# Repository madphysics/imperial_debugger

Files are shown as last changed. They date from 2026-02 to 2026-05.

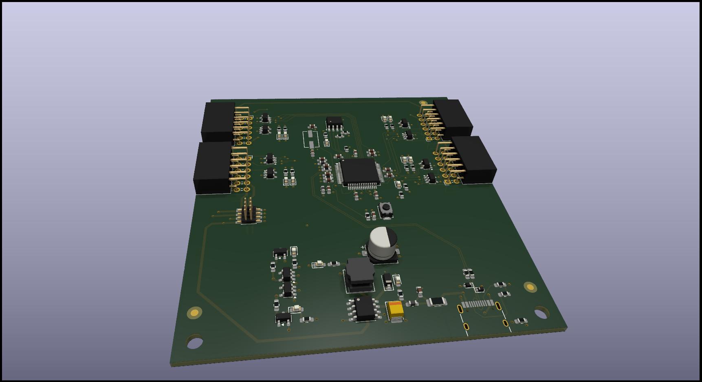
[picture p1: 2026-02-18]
imperial_debugger.jpg

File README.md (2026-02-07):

View this project on [CADLAB.io](https://cadlab.io/project/1894). 

# Imperial Debugger V1.1 #

USB Based multi serial port adaptor

## Overview ##

Based on an FTDI FT4232HL USB to serial chip, with 4 ports. 

The plan is to bring all points to bring them out to a standard 2x6 header

Then can use external daughter boards to do things like:

 * 1x RS232 with hardware flow control
 * 1x RS422/485 with configuration to switch between the two, wither in software or hardware.
 * 1x RS232/422 selectable
 * 1x Logic level, with external level shifter (selectable to internal 3v3)
  
## Power Supply ##

Simple switching mode from 5V USB to 3v3 on the board.
 
## Potential XCVR chips

### RS232
  * TI MAX3222E -- Looks good. Has protection in it. 250k min speeds.
    * MAX3222EEWN is WideSOIC
	  * Also available in SSOP 20 pin, which is harder to solder.
    * 4 signals, so TX/RX and CTS/RTS
	* 3222 has a shutdown pin, Active Low.

### RS422/485

  * MAX3491E
  * MAX22503
  * MAX3070-3073-3076 (3076 is fastest, all pin compatible)
  * SP330 (can do 232 as well, so could use just 3 of these?)
  
### Logic level
 
  * Ideally we want to go from 3v3 ->5V but also 3v3 > lower (2.5, 1.8)
  * LSF0204, can do 3v3 down to Ref\_A. Ref\_B Is always the higher
  * To generate 3v3 > 5V need a different route, where the signals are reversed
    Such that the input is on the Ref_B side, so could use 2 sets and jumper it.
	* Could use 3 pin jumpers, to direct the signal to one of two, or maybe use
	bus selector chip to auto do it.
  * Most ttl/cmos all work the same.

  * LSF0102 - nexperia
  * NCA9306DC - nexperia

## Potential PSU design

 * LM2594M
   * In stock, cheap.
   * ~500mA Output
   * -- **Initial choice**
 * MIC4680
   * In stock.
   * ~1A output
 * TPS5403
   * Hard to get hold of, but in stock.
 * LT1506
   * Expensive. Hard to get.
   
## Notes

 * Use externnal eeprom (SPI based) this will allow the usage of the nRI as a TXEN line for RS422/485 usage
   * 93LC56B is recommended. 16bit wide 2Kb eeprom.

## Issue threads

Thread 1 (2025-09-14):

Create new design idea.

madphysics, 2025-09-14:
Want to go with a base board, and then sub boards for the different output formats.

* Base board does ttl 3v3 output. Exports the signal, 5v, 2v5 and 1v8 voltage rails, together with grounds.
* Sub boards with standard connector that can then  do rs232, rs422/485 or just ttl stuff. voltages can then be decided on the subboards.

Sub boards can be simple sub-projects.

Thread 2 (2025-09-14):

Remove output stages from main board

madphysics, 2025-09-14:
Strip off the transceivers.
Base board should just have some simple protection for esd on the lines, and have ttl 3v3 outputs via header and also a simple board to board connector.
 * Connector to be decided.

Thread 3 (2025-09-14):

TTL output stage

madphysics, 2025-09-14:
Simple TTL output stage board

Input is 3v3, but can output 5v, 2v5 or 1v8 as well as 3v3.
voltage rails are provided by the input connector

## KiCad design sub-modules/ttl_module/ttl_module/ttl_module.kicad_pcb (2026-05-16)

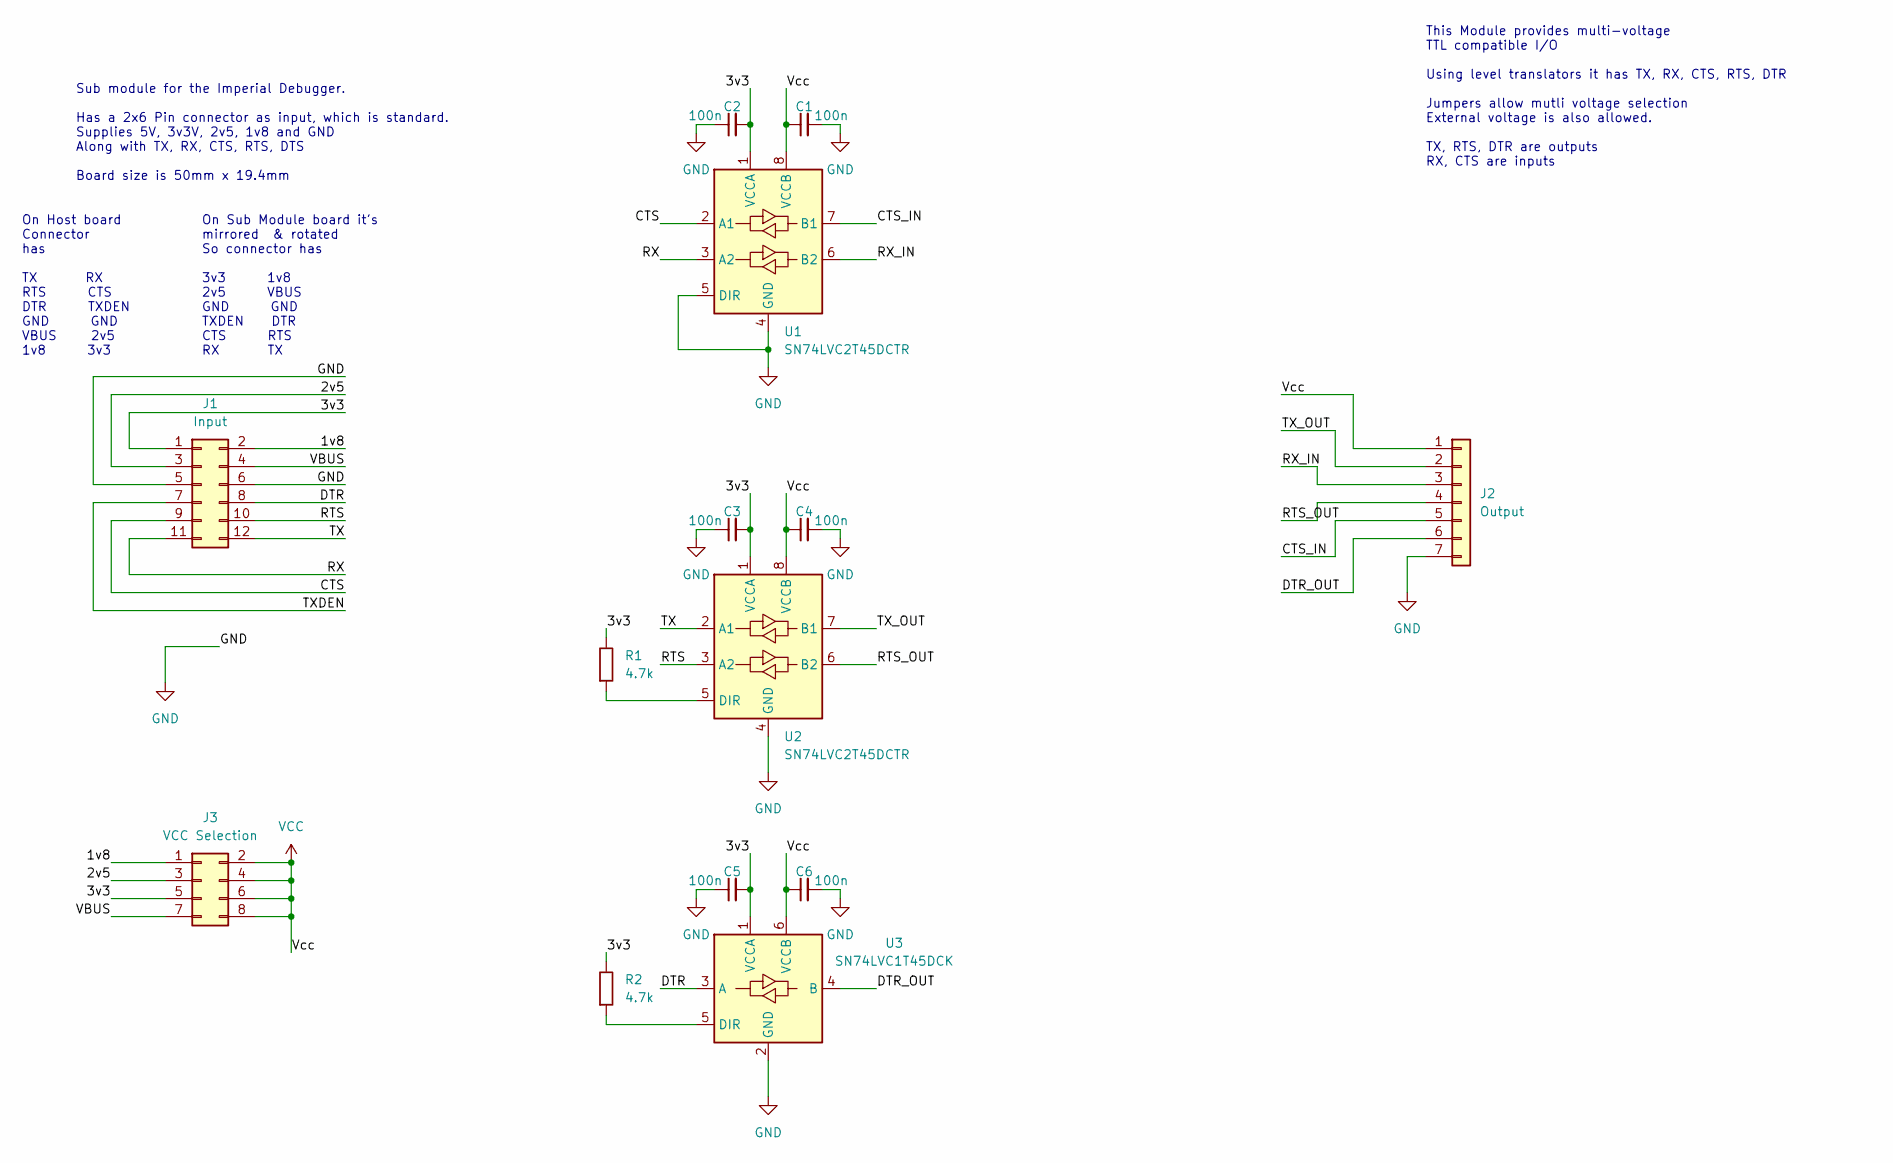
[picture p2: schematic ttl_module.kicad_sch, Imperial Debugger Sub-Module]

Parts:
C1, C2, C3, C4, C5, C6: 100n; C_0603_1608Metric_Pad1.08x0.95mm_HandSolder
J1: Input; PinSocket_2x06_P2.54mm_Horizontal
J2: Output; PinHeader_1x07_P2.54mm_Vertical
J3: VCC Selection; PinHeader_2x04_P2.54mm_Vertical
R1, R2: 4.7k; R_0603_1608Metric_Pad0.98x0.95mm_HandSolder
U1, U2: SN74LVC2T45DCTR; SOP65P400X130-8N
U3: SN74LVC1T45DCK; SOT-363_SC-70-6

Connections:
/1v8: J1.2, J3.1
/2v5: J1.3, J3.3
/3v3: C2.2, C3.2, C5.2, J1.1, J3.5, R1.2, R2.2, U1.1 (VCCA), U2.1 (VCCA), U3.1 (VCCA)
/CTS: J1.9, U1.2 (A1)
/CTS_IN: J2.5, U1.7 (B1)
/DTR: J1.8, U3.3 (A)
/DTR_OUT: J2.6, U3.4 (B)
/RTS: J1.10, U2.3 (A2)
/RTS_OUT: J2.4, U2.6 (B2)
/RX: J1.11, U1.3 (A2)
/RX_IN: J2.3, U1.6 (B2)
/TX: J1.12, U2.2 (A1)
/TXDEN: J1.7
/TX_OUT: J2.2, U2.7 (B1)
/VBUS: J1.4, J3.7
GND: C1.2, C2.1, C3.1, C4.2, C5.1, C6.2, J1.5, J1.6, J2.7, U1.4 (GND), U1.5 (DIR), U2.4 (GND), U3.2 (GND)
unnamed: R1.1, U2.5 (DIR)
unnamed: R2.1, U3.5 (DIR)
VCC: C1.1, C4.1, C6.1, J2.1, J3.2, J3.4, J3.6, J3.8, U1.8 (VCCB), U2.8 (VCCB), U3.6 (VCCB)

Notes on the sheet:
Sub module for the Imperial Debugger. Has a 2x6 Pin connector as input, which is standard. Supplies 5V, 3v3V, 2v5, 1v8 and GND Along with TX, RX, CTS, RTS, DTS Board size is 50mm x 19.4mm
On Host board Connector has TX RX RTS CTS DTR TXDEN GND GND VBUS 2v5 1v8 3v3
This Module provides multi-voltage TTL compatible I/O Using level translators it has TX, RX, CTS, RTS, DTR Jumpers allow mutli voltage selection External voltage is also allowed. TX, RTS, DTR are outputs RX, CTS are inputs
On Sub Module board it's mirrored & rotated So connector has 3v3 1v8 2v5 VBUS GND GND TXDEN DTR CTS RTS RX TX

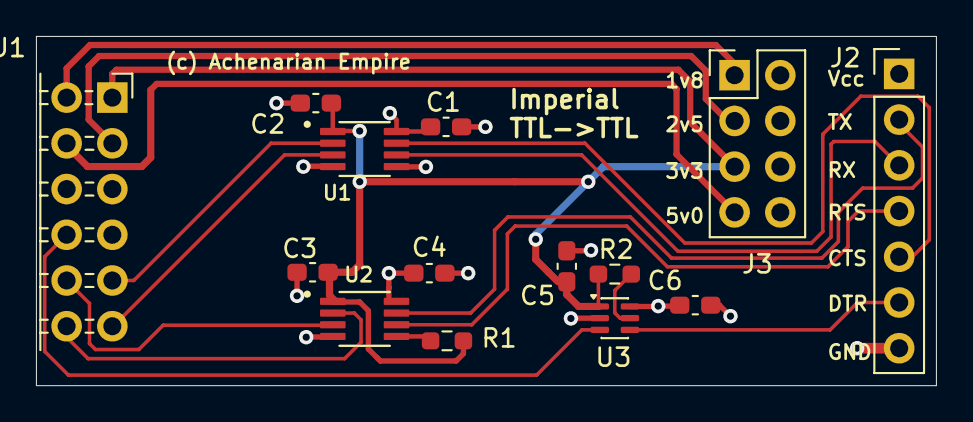
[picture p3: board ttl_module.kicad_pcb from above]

Board: 2 copper layers, 50.0 x 19.4 mm, 14 parts (0 on the bottom side), 18 nets.

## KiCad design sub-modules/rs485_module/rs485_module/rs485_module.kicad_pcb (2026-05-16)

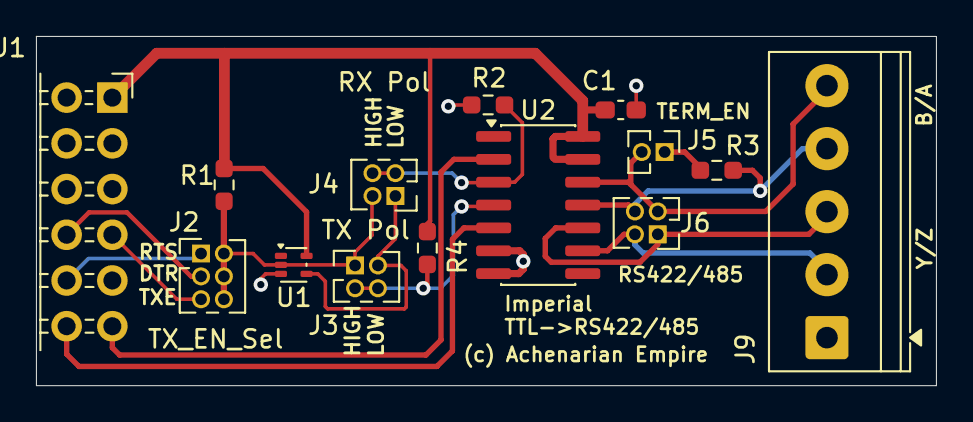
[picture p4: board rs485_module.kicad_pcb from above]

Board: 2 copper layers, 50.0 x 19.4 mm, 14 parts (0 on the bottom side), 16 nets.

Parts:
C1: 100n; C_0603_1608Metric_Pad1.08x0.95mm_HandSolder
J1: Conn_02x06_Odd_Even; PinSocket_2x06_P2.54mm_Horizontal
J2: TX_EN_Sel; PinHeader_2x03_P1.27mm_Vertical
J3: TX Pol; PinHeader_2x02_P1.27mm_Vertical
J4: RX Pol; PinHeader_2x02_P1.27mm_Vertical
J5: TERM_EN; PinHeader_1x02_P1.27mm_Vertical
J6: RS422/485; PinHeader_2x02_P1.27mm_Vertical
J9: MKDS 1/ 5-3,5; TerminalBlock_Phoenix_PT-1,5-5-3.5-H_1x05_P3.50mm_Horizontal
R1, R2, R4: 10k; R_0603_1608Metric_Pad0.98x0.95mm_HandSolder
R3: 120R; R_0603_1608Metric_Pad0.98x0.95mm_HandSolder
U1: 74LVC1GU04DRL; SOT-553
U2: ADM3491ExR; SOIC-14_3.9x8.7mm_P1.27mm

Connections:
+3V3: C1.2, J1.1, R1.1, R4.1, U1.5 (VCC), U2.13 (VCC), U2.14 (VCC)
/A: J5.2, J6.3, J9.5, U2.12 (A)
/B: J6.4, J9.4, R3.2, U2.11 (B)
/DE: J3.3, J3.4, R4.2, U2.4 (DE)
/DTR: J1.8, J2.3
/RTS: J1.10, J2.1
/RX: J1.11, U2.2 (RO)
/TX: J1.12, U2.5 (DI)
/TXDEN: J1.7, J2.5
/TX_EN: J2.2, J2.4, J2.6, J3.1, J4.2, R1.2, U1.2
/Y: J6.2, J9.2, U2.9 (Y)
/Z: J6.1, J9.3, U2.10 (Z)
/~RE: J4.3, J4.4, R2.1, U2.3 (~RE)
/~TX_EN: J3.2, J4.1, U1.4
GND: C1.1, J1.5, J1.6, J9.1, R2.2, U1.3 (GND), U2.6 (GND), U2.7 (GND)
unnamed: J5.1, R3.1

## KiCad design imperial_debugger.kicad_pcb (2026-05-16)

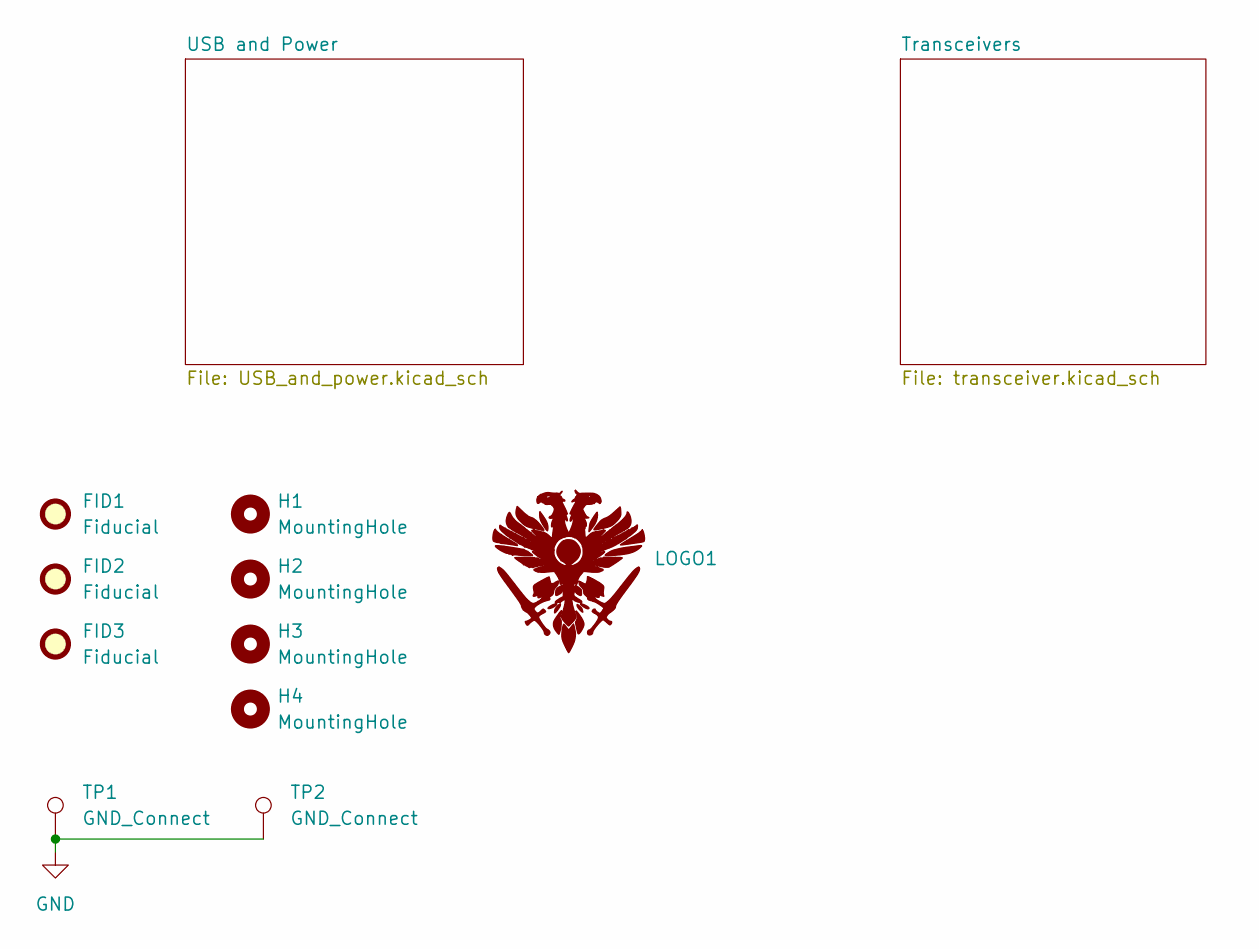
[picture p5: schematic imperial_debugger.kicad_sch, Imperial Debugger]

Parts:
FID1, FID2, FID3: Fiducial; Fiducial_1.5mm_Mask3mm
H1, H2, H3, H4: MountingHole; MountingHole_3.2mm_M3
LOGO1: achenar_logo
TP1, TP2: GND_Connect; TestPoint_Keystone_5000-5004_Miniature

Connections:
GND: TP1.1 (1_1), TP2.1 (1_1); also elsewhere on the board

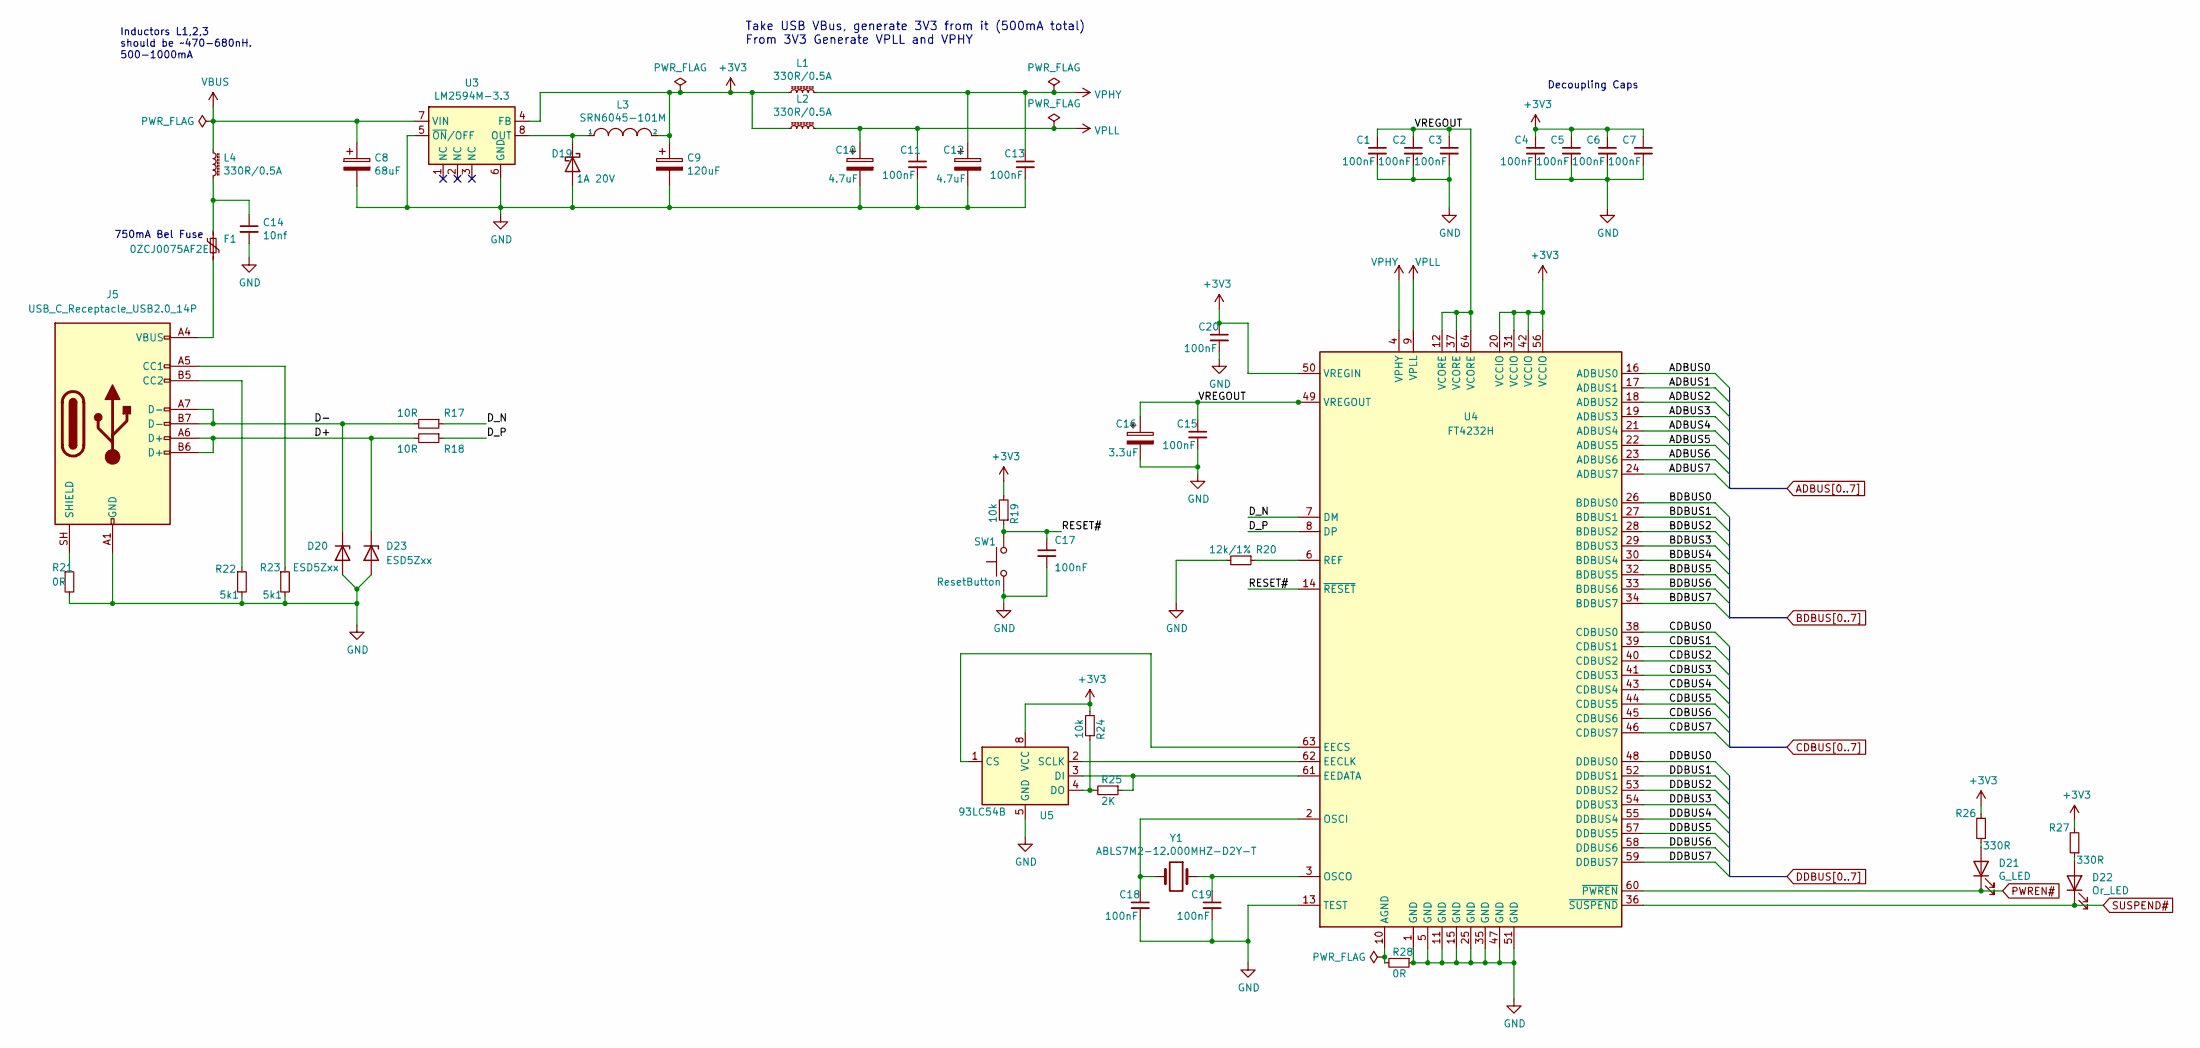
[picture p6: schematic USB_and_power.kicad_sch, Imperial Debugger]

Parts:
C1, C2, C3, C4, C5, C6, C7, C11, C13, C15, C17, C18, C19, C20: 100nF; C_0603_1608Metric_Pad1.08x0.95mm_HandSolder
C8: 68uF; CP_EIA-3528-21_Kemet-B_HandSolder
C9: 120uF; CP_Elec_6.3x5.7
C10, C12: 4.7uF; C_0603_1608Metric_Pad1.08x0.95mm_HandSolder
C14: 10nf; C_0603_1608Metric_Pad1.08x0.95mm_HandSolder
C16: 3.3uF; C_0603_1608Metric_Pad1.08x0.95mm_HandSolder
D19: 1A 20V; D_SOD-123
D20, D23: ESD5Zxx; D_SOD-523
D21: G_LED; LED_0603_1608Metric_Pad1.05x0.95mm_HandSolder
D22: Or_LED; LED_0603_1608Metric_Pad1.05x0.95mm_HandSolder
F1: 0ZCJ0075AF2E; R_1206_3216Metric_Pad1.30x1.75mm_HandSolder
J5: USB_C_Receptacle_USB2.0_14P; USB_C_Receptacle_HRO_TYPE-C-31-M-12
L1, L2, L4: 330R/0.5A; L_0603_1608Metric_Pad1.05x0.95mm_HandSolder
L3: SRN6045-101M; L_Bourns_SRN6045TA
R17, R18: 10R; R_0603_1608Metric_Pad0.98x0.95mm_HandSolder
R19, R24: 10k; R_0603_1608Metric_Pad0.98x0.95mm_HandSolder
R20: 12k/1%; R_0603_1608Metric_Pad0.98x0.95mm_HandSolder
R21, R28: 0R; R_0603_1608Metric_Pad0.98x0.95mm_HandSolder
R22, R23: 5k1; R_0603_1608Metric_Pad0.98x0.95mm_HandSolder
R25: 2K; R_0603_1608Metric_Pad0.98x0.95mm_HandSolder
R26, R27: 330R; R_0603_1608Metric_Pad0.98x0.95mm_HandSolder
SW1: ResetButton; SW_SPST_TS-1088-xR020
U3: LM2594M-3.3; SOIC-8_3.9x4.9mm_P1.27mm
U4: FT4232H; LQFP-64_10x10mm_P0.5mm
U5: 93LC54B; SO-8_3.9x4.9mm_P1.27mm
Y1: ABLS7M2-12.000MHZ-D2Y-T; Crystal_SMD_ECS_CSM3X-2Pin_7.6x4.1mm

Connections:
+3V3: C4.1, C5.1, C6.1, C7.1, C9.1, C20.1, L1.1, L2.1, L3.2, R19.2, R24.2, R26.2, R27.2, U3.4 (FB), U4.20 (VCCIO), U4.31 (VCCIO), U4.42 (VCCIO), U4.50 (VREGIN), U4.56 (VCCIO), U5.8 (VCC); also elsewhere on the board
/USB and Power/D+: D23.1 (K), J5.A6 (D+), J5.B6 (D+), R18.2
/USB and Power/D-: D20.1 (K), J5.A7 (D-), J5.B7 (D-), R17.2
/USB and Power/D_N: R17.1, U4.7 (DM)
/USB and Power/D_P: R18.1, U4.8 (DP)
/USB and Power/RESET#: C17.1, R19.1, SW1.2, U4.14 (~RESET)
/USB and Power/VREGOUT: C1.1, C2.1, C3.1, C15.1, C16.1, U4.12 (VCORE), U4.37 (VCORE), U4.49 (VREGOUT), U4.64 (VCORE)
ADBUS0: U4.16 (ADBUS0); also elsewhere on the board
ADBUS1: U4.17 (ADBUS1); also elsewhere on the board
ADBUS2: U4.18 (ADBUS2); also elsewhere on the board
ADBUS3: U4.19 (ADBUS3); also elsewhere on the board
ADBUS4: U4.21 (ADBUS4); also elsewhere on the board
ADBUS5: U4.22 (ADBUS5)
ADBUS6: U4.23 (ADBUS6)
ADBUS7: U4.24 (ADBUS7); also elsewhere on the board
BDBUS0: U4.26 (BDBUS0); also elsewhere on the board
BDBUS1: U4.27 (BDBUS1); also elsewhere on the board
BDBUS2: U4.28 (BDBUS2); also elsewhere on the board
BDBUS3: U4.29 (BDBUS3); also elsewhere on the board
BDBUS4: U4.30 (BDBUS4); also elsewhere on the board
BDBUS5: U4.32 (BDBUS5)
BDBUS6: U4.33 (BDBUS6)
BDBUS7: U4.34 (BDBUS7); also elsewhere on the board
CDBUS0: U4.38 (CDBUS0); also elsewhere on the board
CDBUS1: U4.39 (CDBUS1); also elsewhere on the board
CDBUS2: U4.40 (CDBUS2); also elsewhere on the board
CDBUS3: U4.41 (CDBUS3); also elsewhere on the board
CDBUS4: U4.43 (CDBUS4); also elsewhere on the board
CDBUS5: U4.44 (CDBUS5)
CDBUS6: U4.45 (CDBUS6)
CDBUS7: U4.46 (CDBUS7); also elsewhere on the board
DDBUS0: U4.48 (DDBUS0); also elsewhere on the board
DDBUS1: U4.52 (DDBUS1); also elsewhere on the board
DDBUS2: U4.53 (DDBUS2); also elsewhere on the board
DDBUS3: U4.54 (DDBUS3); also elsewhere on the board
DDBUS4: U4.55 (DDBUS4); also elsewhere on the board
DDBUS5: U4.57 (DDBUS5)
DDBUS6: U4.58 (DDBUS6)
DDBUS7: U4.59 (DDBUS7); also elsewhere on the board
GND: C1.2, C2.2, C3.2, C4.2, C5.2, C6.2, C7.2, C8.2, C9.2, C10.2, C11.2, C12.2, C13.2, C14.2, C15.2, C16.2, C17.2, C18.2, C19.2, C20.2, D19.2 (A), D20.2 (A), D23.2 (A), J5.A1 (GND), J5.A12 (GND), J5.B1 (GND), J5.B12 (GND), R20.2, R21.2, R22.2, R23.2, R28.1, SW1.1, U3.5 (~ON/OFF), U3.6 (GND), U4.1 (GND), U4.5 (GND), U4.11 (GND), U4.13 (TEST), U4.15 (GND), U4.25 (GND), U4.35 (GND), U4.47 (GND), U4.51 (GND), U5.5 (GND); also elsewhere on the board
unnamed: C14.1, F1.1, L4.2
unnamed: D19.1 (K), L3.1, U3.8 (OUT)
unnamed: D21.2 (A), R26.1
unnamed: D22.2 (A), R27.1
unnamed: F1.2, J5.A4 (VBUS), J5.A9 (VBUS), J5.B4 (VBUS), J5.B9 (VBUS)
unnamed: J5.A5 (CC1), R23.1
unnamed: J5.B5 (CC2), R22.1
unnamed: J5.SH (SHIELD), R21.1
unnamed: R28.2, U4.10 (AGND)
unnamed: U4.62 (EECLK), U5.2 (SCLK)
unnamed: U4.63 (EECS), U5.1 (CS)
unnamed: R25.1, U4.61 (EEDATA), U5.3 (DI)
unnamed: C18.1, U4.2 (OSCI), Y1.2
unnamed: C19.1, U4.3 (OSCO), Y1.1
unnamed: R20.1, U4.6 (REF)
unnamed: R24.1, R25.2, U5.4 (DO)
PWREN#: D21.1 (K), U4.60 (~PWREN); also elsewhere on the board
SUSPEND#: D22.1 (K), U4.36 (~SUSPEND); also elsewhere on the board
VBUS: C8.1, L4.1, U3.7 (VIN); also elsewhere on the board
VPHY: C12.1, C13.1, L1.2, U4.4 (VPHY)
VPLL: C10.1, C11.1, L2.2, U4.9 (VPLL)

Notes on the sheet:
Decoupling Caps
Take USB VBus, generate 3V3 from it (500mA total) From 3V3 Generate VPLL and VPHY
750mA Bel Fuse
Inductors L1,2,3 should be ~470-680nH. 500-1000mA

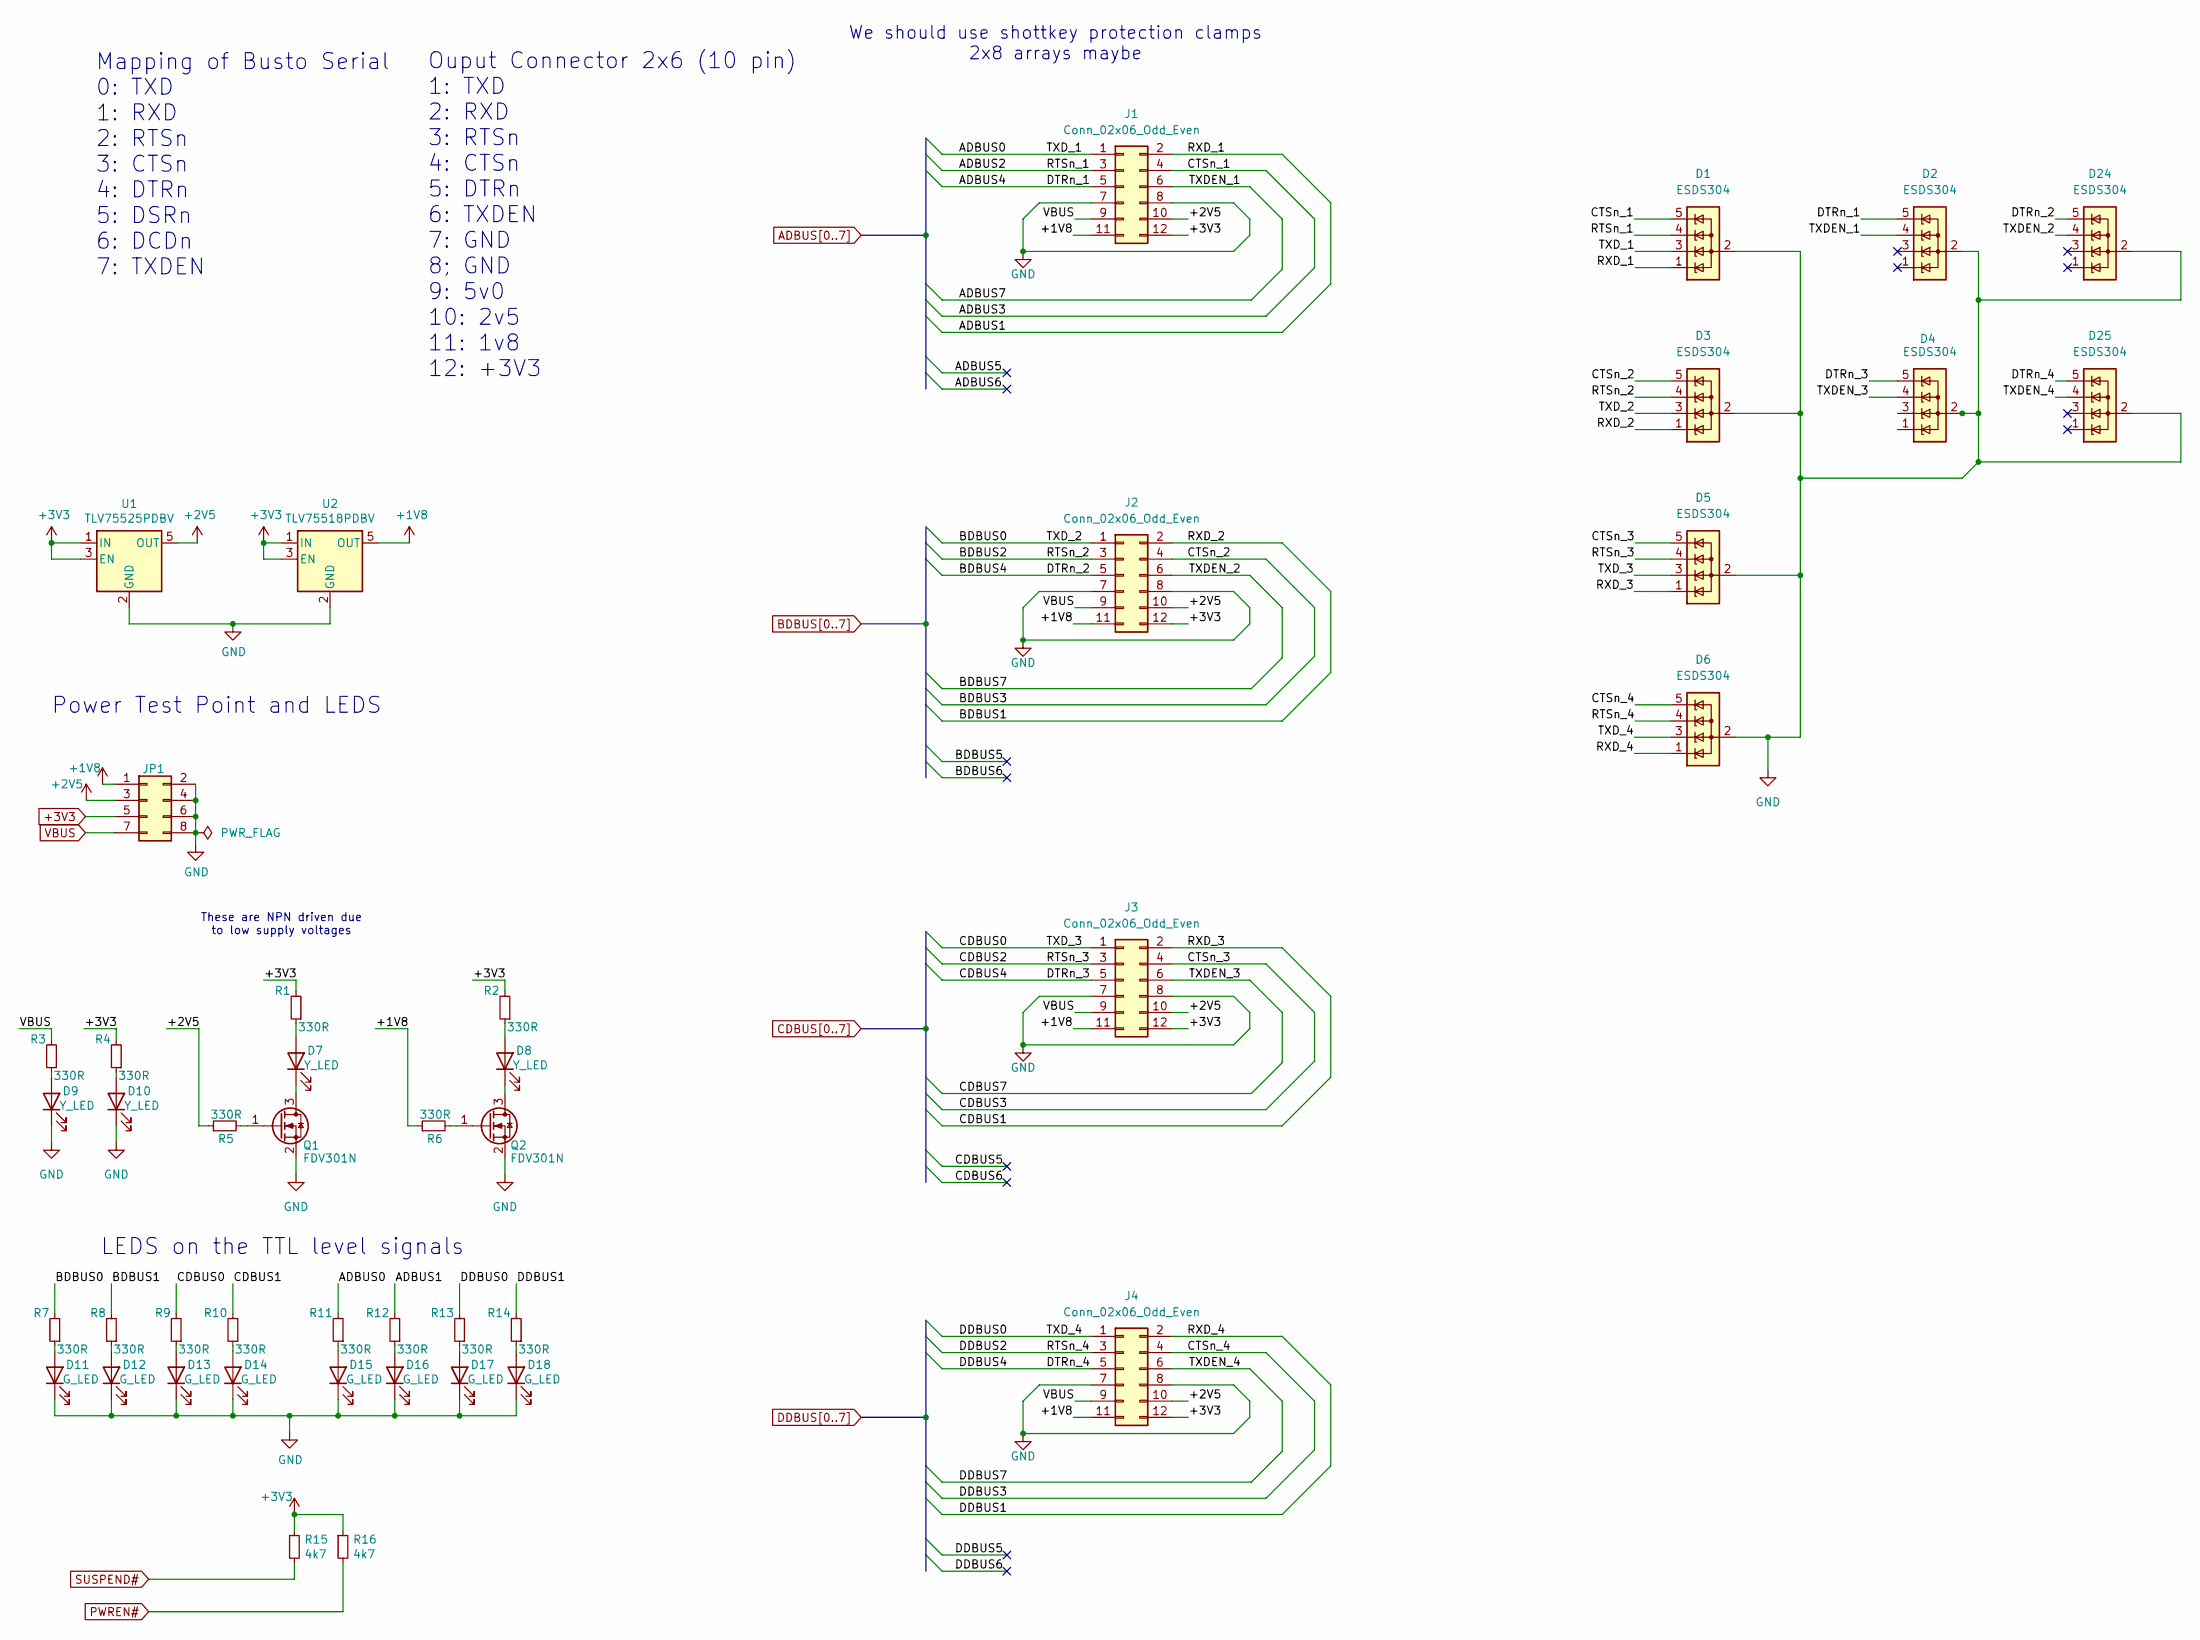
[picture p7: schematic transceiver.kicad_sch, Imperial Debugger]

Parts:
D1, D2, D3, D4, D5, D6, D24, D25: ESDS304; SOT-23-5
D7, D8, D9, D10: Y_LED; LED_0603_1608Metric_Pad1.05x0.95mm_HandSolder
D11, D12, D13, D14, D15, D16, D17, D18: G_LED; LED_0603_1608Metric_Pad1.05x0.95mm_HandSolder
J1, J2, J3, J4: Conn_02x06_Odd_Even; PinSocket_2x06_P2.54mm_Horizontal
JP1: Jumper; PinHeader_2x04_P1.27mm_Vertical_SMD
Q1, Q2: FDV301N; SOT-23
R1, R2, R3, R4, R5, R6, R7, R8, R9, R10, R11, R12, R13, R14: 330R; R_0603_1608Metric_Pad0.98x0.95mm_HandSolder
R15, R16: 4k7; R_0603_1608Metric_Pad0.98x0.95mm_HandSolder
U1: TLV75525PDBV; SOT-23-5
U2: TLV75518PDBV; SOT-23-5

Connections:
+1V8: J1.11, J2.11, J3.11, J4.11, JP1.1, R6.1, U2.5 (OUT)
+2V5: J1.10, J2.10, J3.10, J4.10, JP1.3, R5.1, U1.5 (OUT)
+3V3: J1.12, J2.12, J3.12, J4.12, JP1.5, R1.2, R2.2, R4.2, R15.1, R16.1, U1.1 (IN), U1.3 (EN), U2.1 (IN), U2.3 (EN); also elsewhere on the board
ADBUS0: D1.3 (K), J1.1, R11.2; also elsewhere on the board
ADBUS1: D1.1 (K), J1.2, R12.2; also elsewhere on the board
ADBUS2: D1.4 (K), J1.3; also elsewhere on the board
ADBUS3: D1.5 (K), J1.4; also elsewhere on the board
ADBUS4: D2.5 (K), J1.5; also elsewhere on the board
ADBUS7: D2.4 (K), J1.6; also elsewhere on the board
BDBUS0: D3.3 (K), J2.1, R7.2; also elsewhere on the board
BDBUS1: D3.1 (K), J2.2, R8.2; also elsewhere on the board
BDBUS2: D3.4 (K), J2.3; also elsewhere on the board
BDBUS3: D3.5 (K), J2.4; also elsewhere on the board
BDBUS4: D24.5 (K), J2.5; also elsewhere on the board
BDBUS7: D24.4 (K), J2.6; also elsewhere on the board
CDBUS0: D5.3 (K), J3.1, R9.2; also elsewhere on the board
CDBUS1: D5.1 (K), J3.2, R10.2; also elsewhere on the board
CDBUS2: D5.4 (K), J3.3; also elsewhere on the board
CDBUS3: D5.5 (K), J3.4; also elsewhere on the board
CDBUS4: D4.5 (K), J3.5; also elsewhere on the board
CDBUS7: D4.4 (K), J3.6; also elsewhere on the board
DDBUS0: D6.3 (K), J4.1, R13.2; also elsewhere on the board
DDBUS1: D6.1 (K), J4.2, R14.2; also elsewhere on the board
DDBUS2: D6.4 (K), J4.3; also elsewhere on the board
DDBUS3: D6.5 (K), J4.4; also elsewhere on the board
DDBUS4: D25.5 (K), J4.5; also elsewhere on the board
DDBUS7: D25.4 (K), J4.6; also elsewhere on the board
GND: D1.2 (A), D2.2 (A), D3.2 (A), D4.2 (A), D5.2 (A), D6.2 (A), D9.1 (K), D10.1 (K), D11.1 (K), D12.1 (K), D13.1 (K), D14.1 (K), D15.1 (K), D16.1 (K), D17.1 (K), D18.1 (K), D24.2 (A), D25.2 (A), J1.7, J1.8, J2.7, J2.8, J3.7, J3.8, J4.7, J4.8, JP1.2, JP1.4, JP1.6, JP1.8, Q1.2 (S), Q2.2 (S), U1.2 (GND), U2.2 (GND); also elsewhere on the board
unnamed: D7.2 (A), R1.1
unnamed: D7.1 (K), Q1.3 (D)
unnamed: D8.2 (A), R2.1
unnamed: D8.1 (K), Q2.3 (D)
unnamed: D9.2 (A), R3.1
unnamed: D10.2 (A), R4.1
unnamed: D11.2 (A), R7.1
unnamed: D12.2 (A), R8.1
unnamed: D13.2 (A), R9.1
unnamed: D14.2 (A), R10.1
unnamed: D15.2 (A), R11.1
unnamed: D16.2 (A), R12.1
unnamed: D17.2 (A), R13.1
unnamed: D18.2 (A), R14.1
unnamed: Q1.1 (G), R5.2
unnamed: Q2.1 (G), R6.2
PWREN#: R16.2; also elsewhere on the board
SUSPEND#: R15.2; also elsewhere on the board
VBUS: J1.9, J2.9, J3.9, J4.9, JP1.7, R3.2; also elsewhere on the board

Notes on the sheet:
LEDS on the TTL level signals
Ouput Connector 2x6 (10 pin) 1: TXD 2: RXD 3: RTSn 4: CTSn 5: DTRn 6: TXDEN 7: GND 8; GND 9: 5v0 10: 2v5 11: 1v8 12: +3V3
Power Test Point and LEDS
These are NPN driven due to low supply voltages
We should use shottkey protection clamps 2x8 arrays maybe
Mapping of Busto Serial 0: TXD 1: RXD 2: RTSn 3: CTSn 4: DTRn 5: DSRn 6: DCDn 7: TXDEN

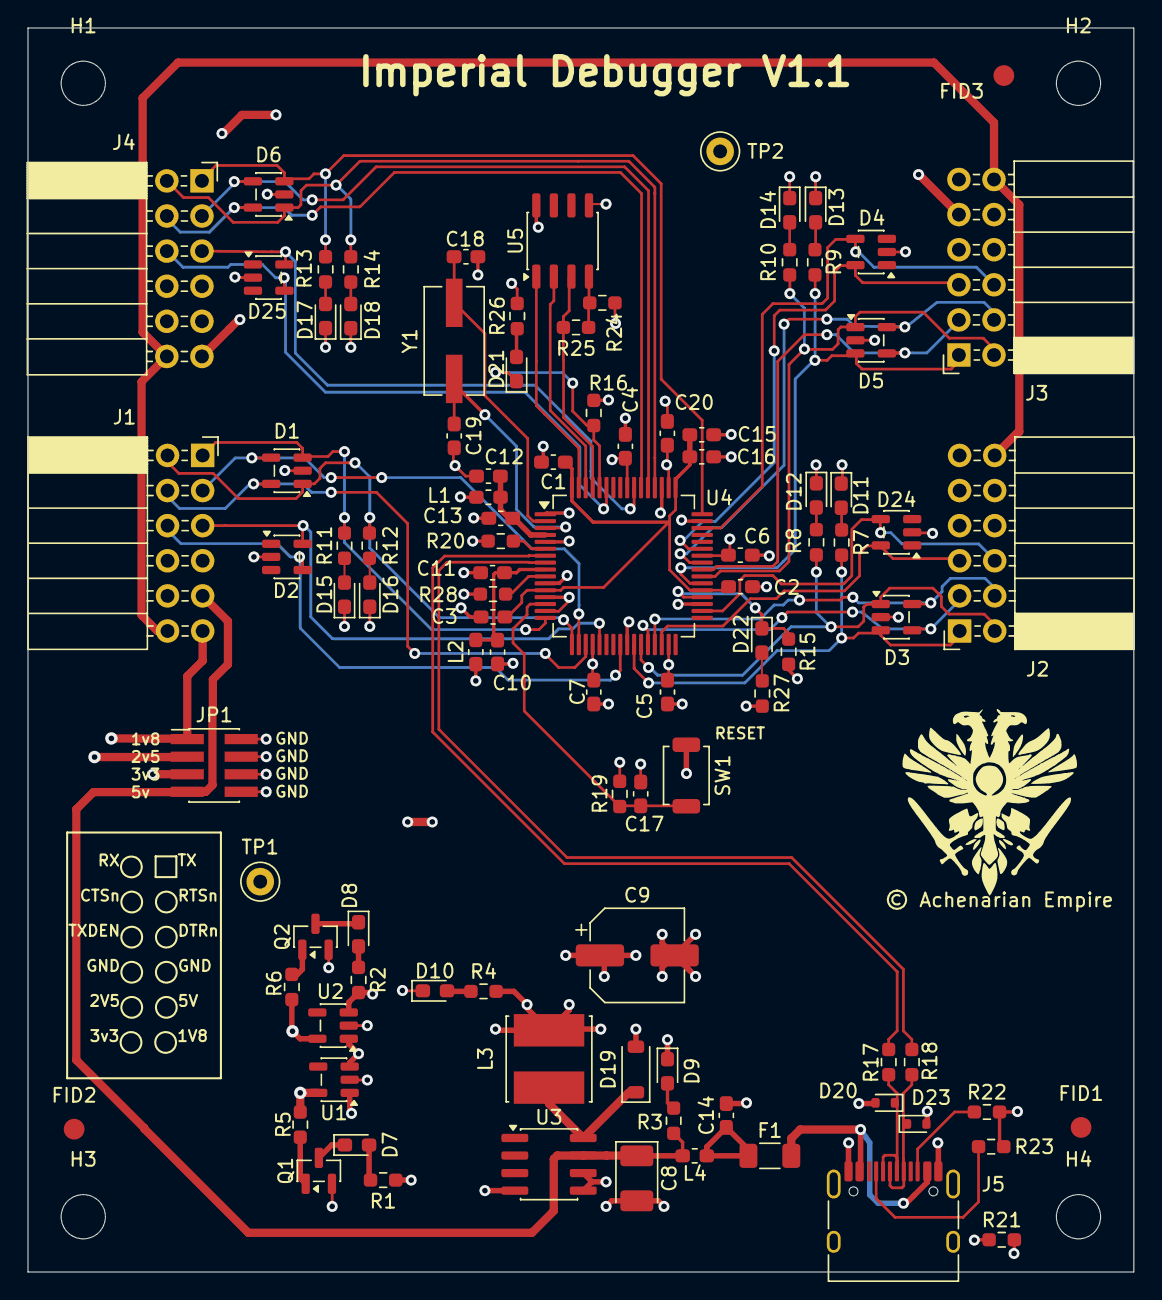
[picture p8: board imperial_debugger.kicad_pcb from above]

Board: 4 copper layers, 80.0 x 90.0 mm, 103 parts (0 on the bottom side), 71 nets.

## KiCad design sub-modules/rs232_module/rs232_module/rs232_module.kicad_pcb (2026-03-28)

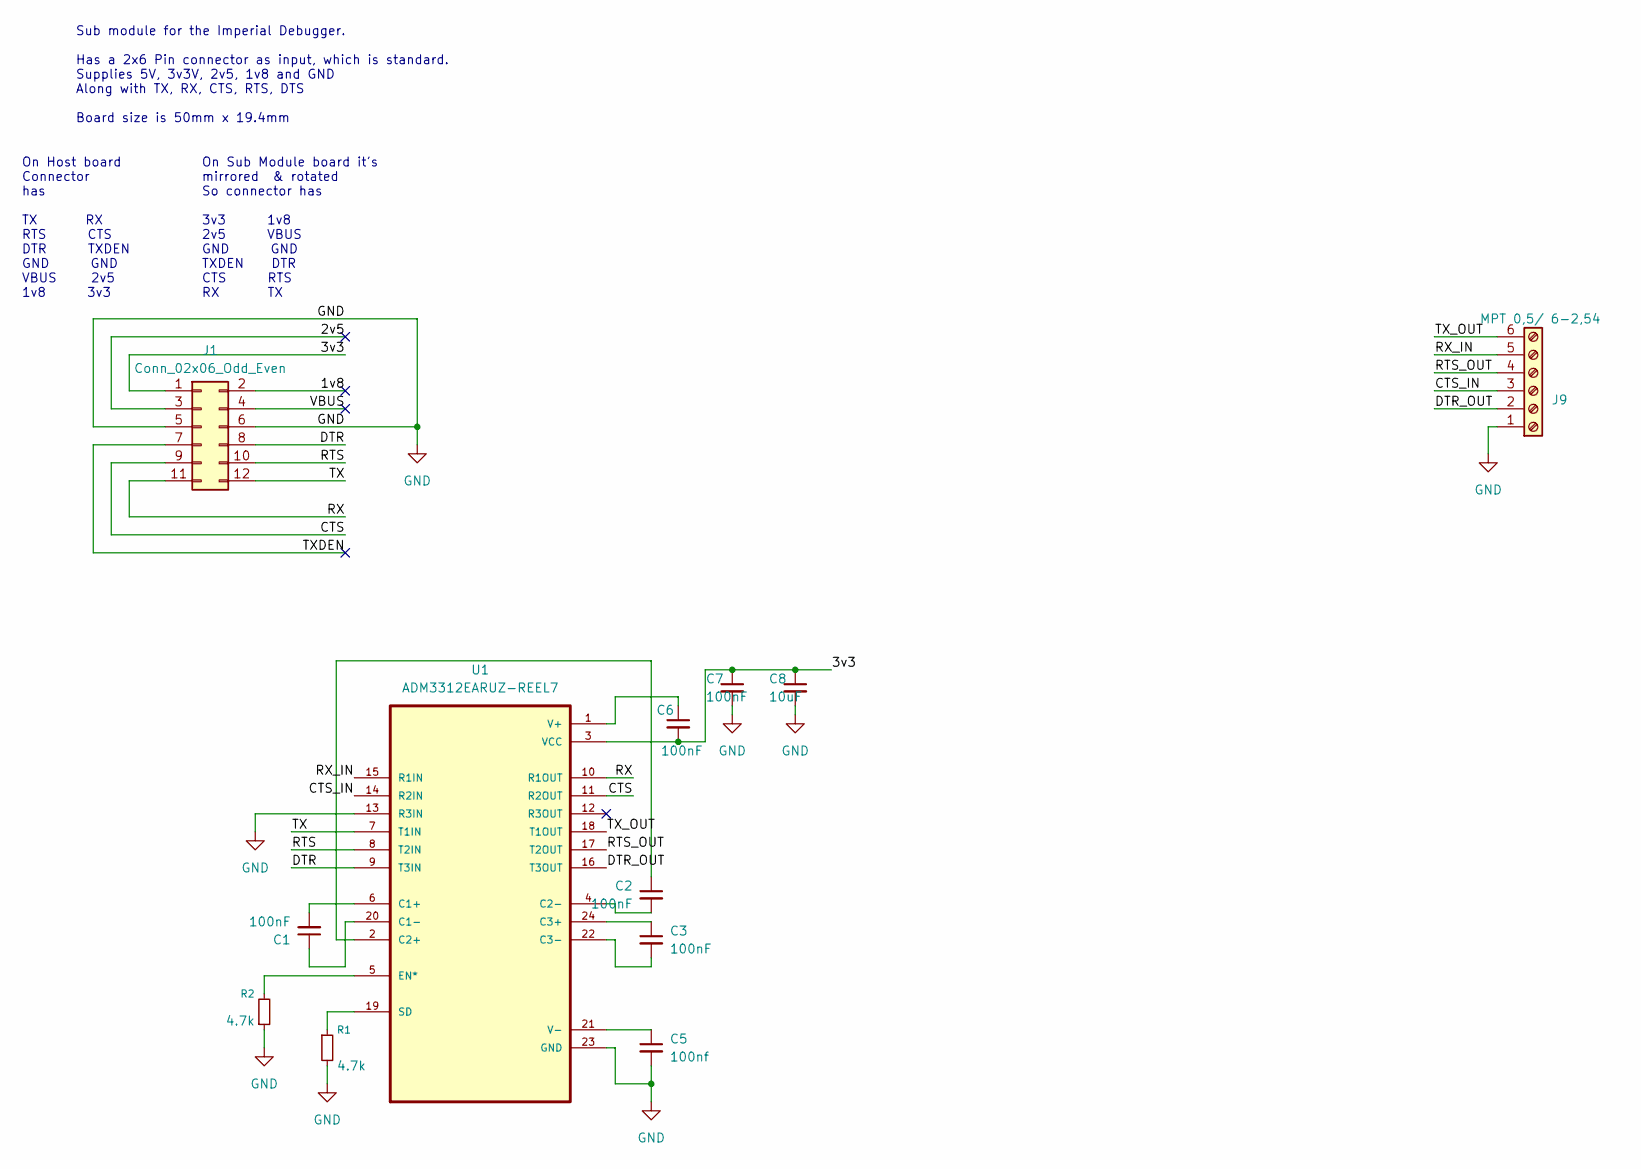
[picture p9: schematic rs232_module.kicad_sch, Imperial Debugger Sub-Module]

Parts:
C1, C2, C3, C6, C7: 100nF; C_0603_1608Metric_Pad1.08x0.95mm_HandSolder
C5: 100nf; C_0603_1608Metric_Pad1.08x0.95mm_HandSolder
C8: 10uF; CP_EIA-3528-12_Kemet-T_HandSolder
J1: Conn_02x06_Odd_Even; PinSocket_2x06_P2.54mm_Horizontal
J9: MPT 0,5/ 6-2,54; TerminalBlock_Phoenix_MPT-0,5-6-2.54_1x06_P2.54mm_Horizontal
R1, R2: 4.7k; R_0603_1608Metric_Pad0.98x0.95mm_HandSolder
U1: ADM3312EARUZ-REEL7; SOP65P640X120-24N; DigiKey_Part_Number 505-ADM3312EARUZ-REEL7CT-ND

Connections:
/1v8: J1.2
/2v5: J1.3
/3v3: C6.2, C7.1, C8.1, J1.1, U1.3 (VCC)
/CTS: J1.9, U1.11 (R2OUT)
/CTS_IN: J9.3, U1.14 (R2IN)
/DTR: J1.8, U1.9 (T3IN)
/DTR_OUT: J9.2, U1.16 (T3OUT)
/RTS: J1.10, U1.8 (T2IN)
/RTS_OUT: J9.4, U1.17 (T2OUT)
/RX: J1.11, U1.10 (R1OUT)
/RX_IN: J9.5, U1.15 (R1IN)
/TX: J1.12, U1.7 (T1IN)
/TXDEN: J1.7
/TX_OUT: J9.6, U1.18 (T1OUT)
/VBUS: J1.4
GND: C5.2, C7.2, C8.2, J1.5, J1.6, J9.1, R1.2, R2.1, U1.13 (R3IN), U1.23 (GND)
unnamed: C1.2, U1.6 (C1+)
unnamed: C1.1, U1.20 (C1-)
unnamed: C2.1, U1.2 (C2+)
unnamed: C2.2, U1.4 (C2-)
unnamed: C3.1, U1.24 (C3+)
unnamed: C3.2, U1.22 (C3-)
unnamed: R2.2, U1.5 (EN*)
unnamed: R1.1, U1.19 (SD)
unnamed: C6.1, U1.1 (V+)
unnamed: C5.1, U1.21 (V-)

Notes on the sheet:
Sub module for the Imperial Debugger. Has a 2x6 Pin connector as input, which is standard. Supplies 5V, 3v3V, 2v5, 1v8 and GND Along with TX, RX, CTS, RTS, DTS Board size is 50mm x 19.4mm
On Host board Connector has TX RX RTS CTS DTR TXDEN GND GND VBUS 2v5 1v8 3v3
On Sub Module board it's mirrored & rotated So connector has 3v3 1v8 2v5 VBUS GND GND TXDEN DTR CTS RTS RX TX

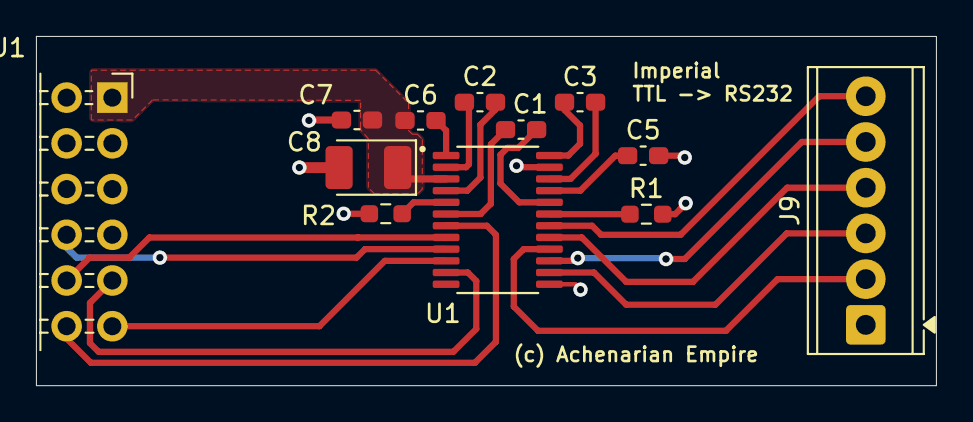
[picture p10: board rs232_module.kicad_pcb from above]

Board: 2 copper layers, 50.0 x 19.4 mm, 12 parts (0 on the bottom side), 22 nets.

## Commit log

2018-05-20 More data sheets, plus LT Spice sim and model for led mosfet.
2018-05-21 Adding design files.
    Schematic and layout starting.
    Some more data sheets being added.
    [FT2232.sch, USB_and_Power.sch, main_board.kicad_pcb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]
2019-06-22 Updates when doing some layout testing
    [FT2232.sch, USB_and_Power.sch, main_board.kicad_pcb]
2021-08-21 Cleaning up.
    Going to do a new design.
    [FT2232.sch, USB_and_Power.sch, main_board.kicad_pcb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]
2021-08-22 Adding in first few pages and some data sheets
    [imperial_debugger.sch, transceiver.sch]
2021-08-22 Project, pcb and lib
    [imperial_debugger.kicad_pcb]
2021-08-22 USB and FTDI chip
    [USB_and_power.sch]
2021-09-05 Updated with the ttl output
    Adding a lot of footprints and other bits.
    Changed TVS on USB
    Added fuse on USB 5V
    TTL level translators, 2x. Go from 3v3 to 1v8, then "anything" to 1v8
    for the output.
    2x LDO for 3v3->1v8, 3v3->2v5
    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
    [USB_and_power.sch, transceiver.sch]
2021-09-19 Adding some LED stuff.
    [USB_and_power.sch, transceiver.sch]
2021-09-19 Added some footprints and started to look at layout
    [USB_and_power.sch, imperial_debugger.kicad_pcb, transceiver.sch]
2021-11-28 Updates as we do routing.
    Changed discrete jumpres to a 2x4 block and 2x3 block, 2mm pitch.
    Started routing each tranciever block
    [USB_and_power.sch, imperial_debugger.kicad_pcb, transceiver.sch]
2021-12-03 Almost fully routed.. lots of DRC's to sort out.
    Also need to get correct pcb parameters to do more checks.
    [USB_and_power.sch, imperial_debugger.kicad_pcb, transceiver.sch]
2022-01-08 Updates with all the routing and moving to kicad 6.0
    [USB_and_power.kicad_sch, imperial_debugger.kicad_pcb, imperial_debugger.kicad_sch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]
2022-01-08 Remove kicad 5.x files.
    [USB_and_power.sch, imperial_debugger.sch, transceiver.sch]
2025-09-14 After update to kicak 9.0
    [USB_and_power.kicad_sch, imperial_debugger.kicad_pcb, imperial_debugger.kicad_sch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]
2025-09-17 Updated to remove the level shifters
    Just have 3v3 ttl outputs for now, trancievers will be on different
    boards
    [USB_and_power.kicad_sch, imperial_debugger.kicad_sch, transceiver.kicad_sch]
2025-12-30 Updated power leds and external protection on Serial
    [USB_and_power.kicad_sch, transceiver.kicad_sch]
2026-02-07 Updated with the new design.
    Removed all level translators.
    4 sockets, 2x6 pin outputs
    New PCB shape and routing
    [USB_and_power.kicad_sch, imperial_debugger.kicad_pcb, imperial_debugger.kicad_sch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]
2026-02-15 Add some info to the master document
    [imperial_debugger.kicad_pcb]
2026-02-15 Add initial new submodule
    Created from our new project template.
    [ttl_module.kicad_pcb, ttl_module.kicad_sch]
2026-02-17 Updated Schematic and PCB for first pass at the design
    [ttl_module.kicad_pcb, ttl_module.kicad_sch]
2026-03-08 Add rs485/422 module
    Has a custom 2x6 pin connector in a local library
    [rs485_module.kicad_pcb, rs485_module.kicad_sch]
2026-03-08 Quick update to the ttl module board layout
    [ttl_module.kicad_pcb]
2026-03-08 Add rs232 module
    [rs232_module.kicad_pcb, rs232_module.kicad_sch]
2026-03-08 Add the updated pin socket to the local library on the ttl submodule
2026-03-28 Update schematics after moving to KiCad 10
    Added some footprints to a local lib, as the silkscreen caused issues.
    [USB_and_power.kicad_sch, imperial_debugger.kicad_pcb, imperial_debugger.kicad_sch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]
2026-04-12 Update USB routing
    [imperial_debugger.kicad_pcb]
2026-05-16 Sorting out BOMs
    [USB_and_power.kicad_sch, imperial_debugger.kicad_sch, rs232_module.kicad_sch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]
2026-07-01 BOM updates. Things needed changing due to availability
    Tant Caps
    Schotkey diodes
    Pushbutton Switch
    [USB_and_power.kicad_sch]
2026-08-06 Adding some Alt suppliers for suppler pns
    [USB_and_power.kicad_sch, imperial_debugger.kicad_sch, rs232_module.kicad_sch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]
2026-08-15 Update oscillator caps
    Replaced with correct 27pf in schematic
    [USB_and_power.kicad_sch]
2026-08-15 Update Alt suppliers for UK/EU ones
    [USB_and_power.kicad_sch, imperial_debugger.kicad_sch, transceiver.kicad_sch]

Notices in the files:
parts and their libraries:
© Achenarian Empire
